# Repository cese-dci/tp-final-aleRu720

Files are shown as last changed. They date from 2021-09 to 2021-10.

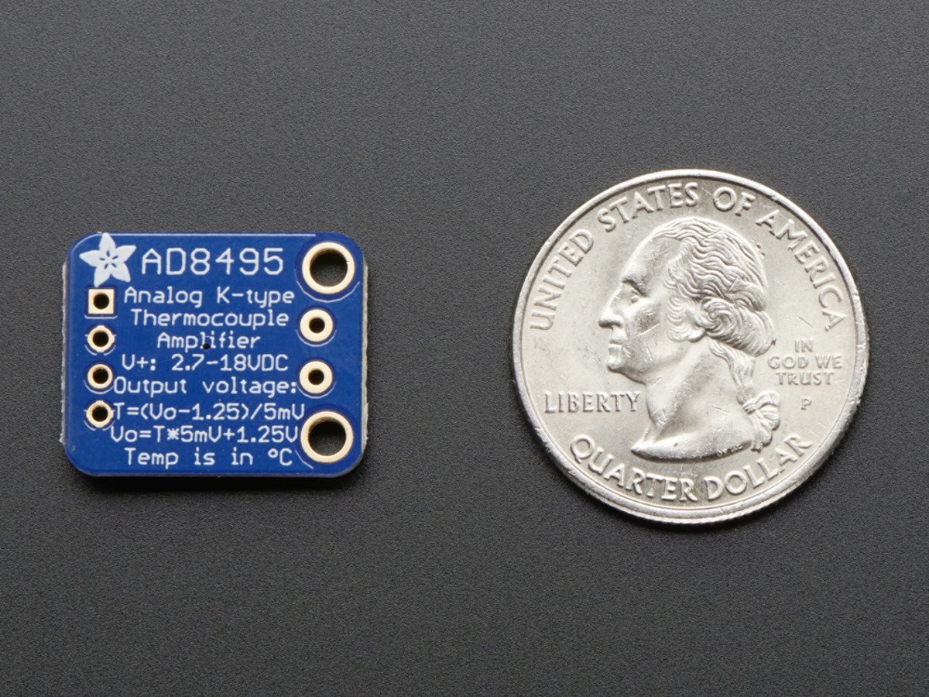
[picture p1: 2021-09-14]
doc/propuesta/adafruit_products_AD8495_Back.jpg

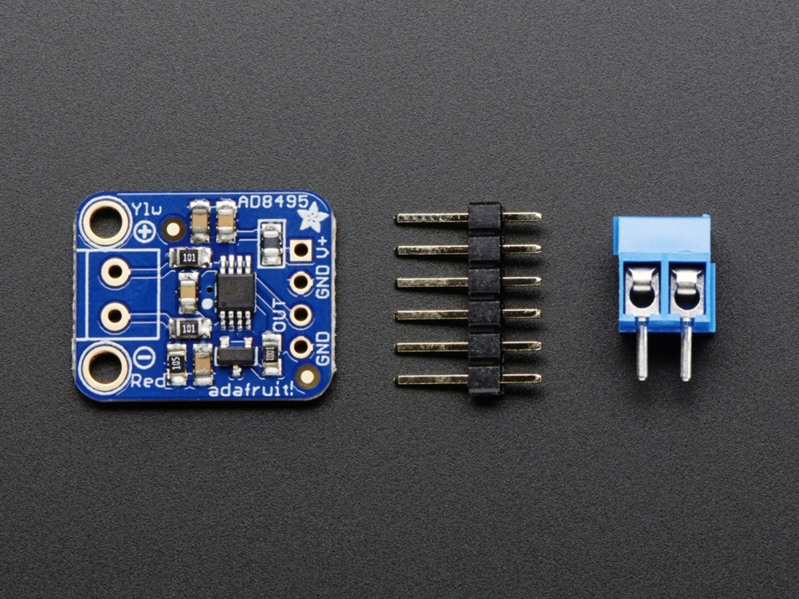
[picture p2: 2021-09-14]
doc/propuesta/adafruit_products_AD8495_Top_Header.jpg

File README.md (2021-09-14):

## Trabajo práctico final de la asignatura DCI ##
Este repositorio contiene el trabajo práctico final para la asignatura de Diseño de Circuitos Impresos de la carrera de posgrado de FIUBA.

* Autor: Ing. Alejandro Rougier
* Título corto del trabajo:  Réplica AD8495 K-type thermocouple amplifier
* Descripción: 
Amplificador para termocupla tipo K, con salida analógica, basado en el amplificador de precisión para termocuplas, con compensación de unión fría AD8495 de Analog Device

## Licencia de este trabajo ##
Se utiliza la licencia CERN-OHL-P v2

## Estructura del TP FINAL ##

* doc: 
  * Notas de ingeniería propias.
  * Notas de aplicación propias.
  * Estudios previos, estado del arte, resumen de las investigaciones.
  * Notas con cálculos.
  * Dibujos adicionales.
  * Fotos de los prototipos.
  * Presupuestos, cotizaciones.
* info: 
  * Hojas de datos.
  * Notas de aplicación.
  * Info de productos comerciales.
  * Info en internet.
* pcb: Archivos de diseño esquemático y pcb.

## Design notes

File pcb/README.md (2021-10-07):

# Archivos Kicad #

## Contenido del Directorio:

El directorio contine 2 carpetas, **ProyectoFinalRougier_v1** y **ProyectoFinalRougier_v2**

Ambas carpetas continen en su interior los siguientes archivos:

* Archivos de proyecto.
* Esquemático.
* PCB.
* Modelos  3D( archivo.wrl).

Difieren entre sí en la disposición de los componentes en el PCB. Esto se hizo así porque el proyecto es una réplica de un amplificador de 
termocuplas de la firma ***ADAFRUIT***. 
El original, es para una sola termocupla, la réplica se pidió para dos termocuplas por lo que el circuito se duplicaba.

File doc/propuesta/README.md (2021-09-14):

## Archivos de la Propuesta ##

* Imágenes de la placa de ambos lados. 
* Urls, archivo con link al sitio del dispositivo. 
* Imagen del circuito esquemático de referencia.
* Hoja de datos del componente principal

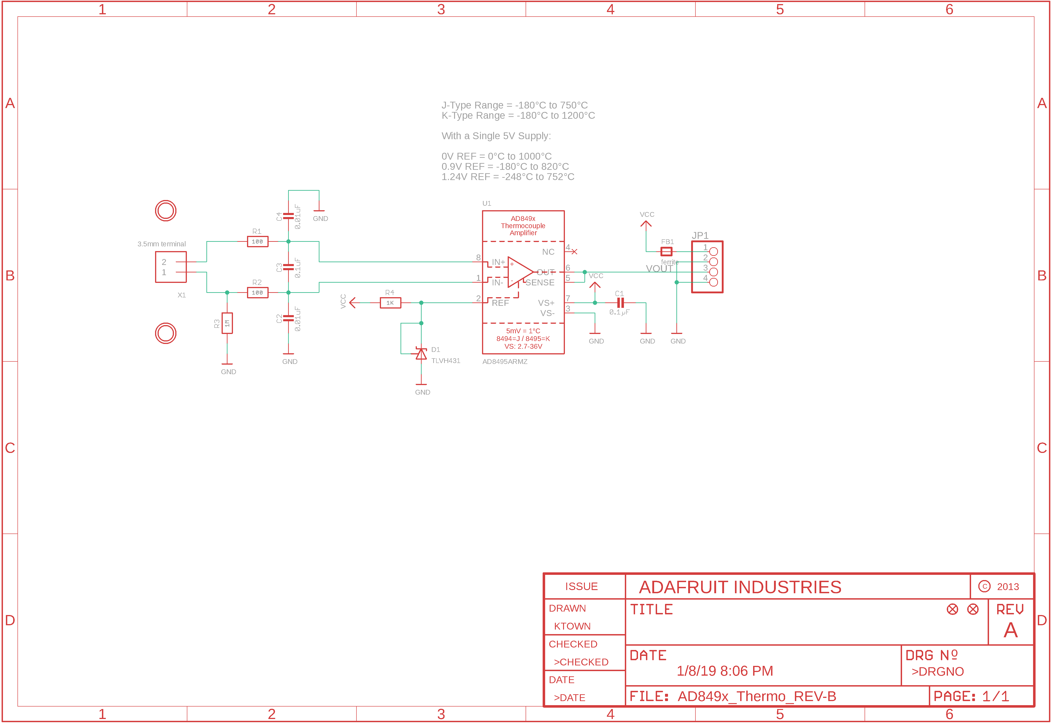
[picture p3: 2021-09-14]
doc/propuesta/adafruit_products_AD8495_Sch.png

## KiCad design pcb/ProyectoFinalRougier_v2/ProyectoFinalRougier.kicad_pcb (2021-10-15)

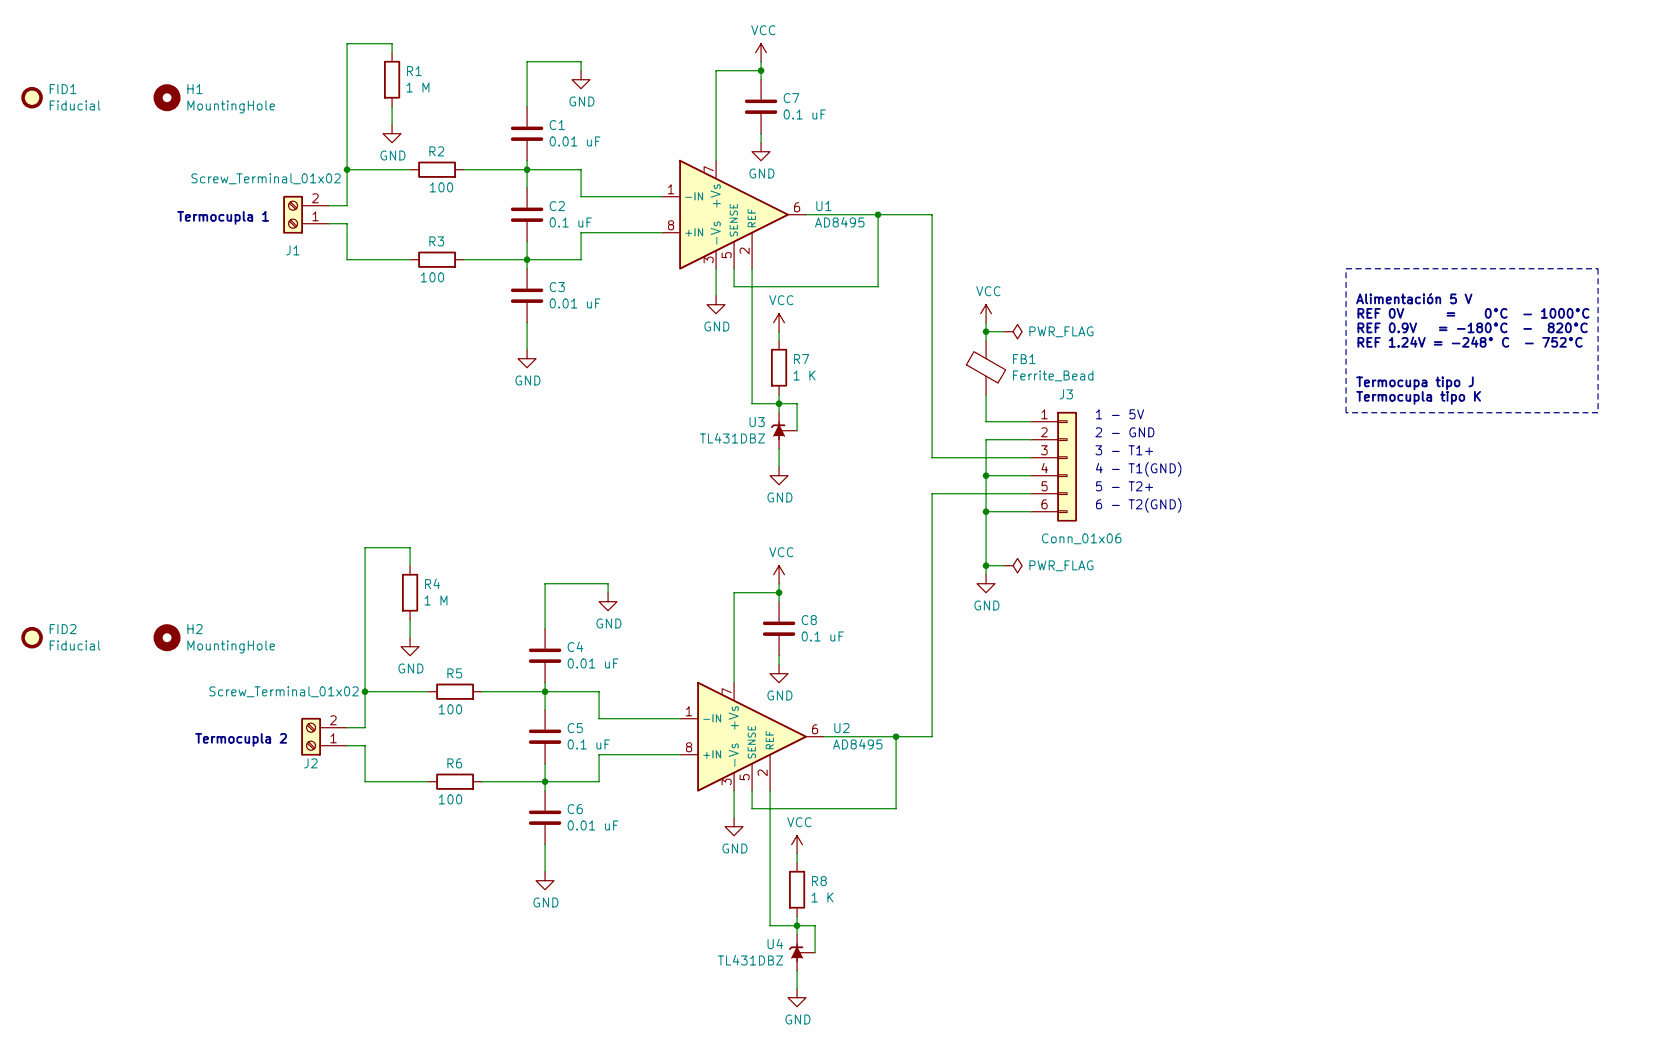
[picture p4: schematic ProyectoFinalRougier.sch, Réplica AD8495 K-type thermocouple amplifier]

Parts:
C1, C3, C4, C6: 0.01 uF; C_0805_2012Metric
C2, C5, C7, C8: 0.1 uF; C_0805_2012Metric
FB1: Ferrite_Bead; D_0805_2012Metric
FID1, FID2: Fiducial; Fiducial_0.75mm_Mask2.25mm
H1, H2: MountingHole; MountingHole_2.5mm
J1, J2: Screw_Terminal_01x02; TerminalBlock_Phoenix_PT-1,5-2-3.5-H_1x02_P3.50mm_Horizontal; Mouser Cod: 651-1888807
J3: Conn_01x06; PinHeader_1x06_P2.54mm_Vertical
R1, R4: 1 M; R_0805_2012Metric
R2, R3, R5, R6: 100; R_0805_2012Metric
R7, R8: 1 K; R_0805_2012Metric
U1, U2: AD8495; MSOP-8_3x3mm_P0.65mm; Mouser Cod: 584-AD8495ARMZ-R7
U3, U4: TL431DBZ; SOT-23; Mouser Cod: 595-TL431BIDBZR

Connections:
GND: C1.1, C3.2, C4.1, C6.2, C7.2, C8.2, J3.2, J3.4, J3.6, R1.2, R4.2, U1.3 (-Vs), U2.3 (-Vs), U3.3 (A), U4.3 (A)
unnamed: C1.2, C2.1, R2.2, U1.1 (-IN)
unnamed: C2.2, C3.1, R3.2, U1.8 (+IN)
unnamed: C4.2, C5.1, R5.2, U2.1 (-IN)
unnamed: C5.2, C6.1, R6.2, U2.8 (+IN)
unnamed: FB1.2, J3.1
unnamed: J1.1, R3.1
unnamed: J1.2, R1.1, R2.1
unnamed: J2.1, R6.1
unnamed: J2.2, R4.1, R5.1
unnamed: J3.3, U1.5 (SENSE), U1.6
unnamed: J3.5, U2.5 (SENSE), U2.6
unnamed: R7.2, U1.2 (REF), U3.1 (K), U3.2 (REF)
unnamed: R8.2, U2.2 (REF), U4.1 (K), U4.2 (REF)
VCC: C7.1, C8.1, FB1.1, R7.1, R8.1, U1.7 (+Vs), U2.7 (+Vs)

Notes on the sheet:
Termocupa tipo J Termocupla tipo K
Termocupla 2
Alimentación 5 V REF 0V = 0°C - 1000°C REF 0.9V = -180°C - 820°C REF 1.24V = -248° C - 752°C
Termocupla 1
1 - 5V
2 - GND
3 - T1+
4 - T1(GND)
5 - T2+
6 - T2(GND)

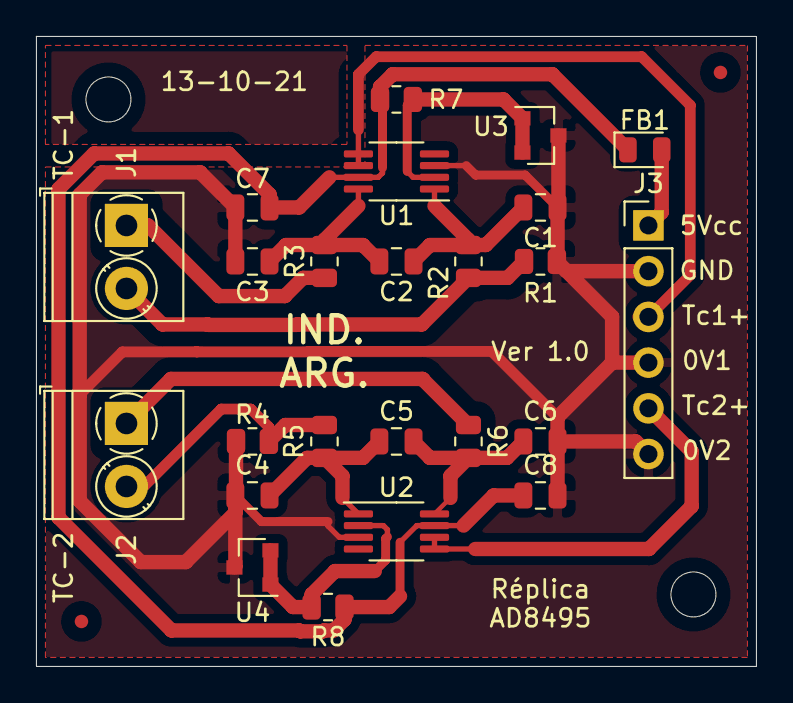
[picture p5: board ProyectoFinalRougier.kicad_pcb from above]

Board: 2 copper layers, 40.0 x 35.0 mm, 28 parts (0 on the bottom side), 15 nets.

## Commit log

2021-09-14 Se agregan los archivos de la propuesta
2021-09-14 Se agrega la Licencia
2021-09-20 Se agrega el esquemático completo, con la asociación de huellas y los valores de componentes. Se ejecutó ECR y se corrigieron los warning
    [ProyectoFinalRougier.kicad_pcb, ProyectoFinalRougier.sch]
2021-09-22 Se agregan Fiduciales y Mounting hole, se corrige ubicación de algunos componentes
    [ProyectoFinalRougier.sch]
2021-10-07 Se agregan 2 carpetas con el mismo proyecto pero con distinta disposición del PCB.
    [ProyectoFinalRougier.kicad_pcb, ProyectoFinalRougier.sch]
2021-10-13 Se agregan comentarios adicionales al PCB
    [ProyectoFinalRougier.kicad_pcb]
2021-10-13 Se agregan etiquetas y comentarios a los dos PCBs
    [ProyectoFinalRougier.kicad_pcb]
2021-10-15 Ajuste del Margen, se aumentó el menor margen que limita el AD8495
    [ProyectoFinalRougier.kicad_pcb]
